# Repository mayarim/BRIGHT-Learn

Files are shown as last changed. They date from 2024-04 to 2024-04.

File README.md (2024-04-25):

# BRIGHT-Learn: Building Responsive Interactions for Growth, Healing, and Therapeutic Learning
### Custom-designed toy for a developmentally disabled child in order to facilitate comfort and enjoyment of occupational therapy activities.

Marin_Poster

## Source code: 
I used FastLED and SerialMP3Player Arduino libraries and wrote a program, Game.ino, integrating these into a game loop. The toy welcomes Marin to teh game, then prompts her to press the button of a random color. If she pressees the correct one, then the toy says "Good job" and a song plays to reward her. If she presses the incorrect one, the lights guide her towards the correct section. Currently, the code is rather disorganized, but future plans include re-factoring to create a "color" struct with various fields and filepaths in order to streamline readability. Additionally, more code will be introduced in later iterations to make the game loop more exciting and engaging. 

## 3D Models: 
The physical casing for the toy was constructed using a modular design of six "box segment" pieces around one "pie core" piece. The central core piece has columns that hold a stand for the speaker to rest on, so that it can be closer to the lid and allow more sound to pass through. All 3D models were created in Solidworks. The lid was laser cut from 1/8" plywood, then painted with a different color for each of six sections. In order to let the 3D strip lights show through from the inside, small "window" slots were cut out, and corresponding "windows" were cut out of 1/8" clear acrylic and press fit inside to make the lights visible. The cad_models folder includes all .stl and .sldprt files of 3D-printed parts, .dxf files for laser-cut parts, and a .sldasm file showing the assembly. 

## Components used: 
* Arduino Mega 2650: https://store.arduino.cc/products/arduino-mega-2560-rev3
  


* LM386 Audio Amplifier https://www.ti.com/lit/ds/symlink/lm386.pdf
  


* HiLetgo GD3300 UART Control Serial MP3 Music Player Module https://github.com/salvadorrueda/SerialMP3Player



* BTF-LIGHTING WS2812B RGB ECO LED Strip https://github.com/FastLED/FastLED/



* Arcade-style push-buttons



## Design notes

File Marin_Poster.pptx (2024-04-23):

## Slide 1

BRIGHT Learn
Building Responsive Interactions for Growth, Healing, and Therapeutic Learning
Mayari Merchant, John Board, Ph.D.
Duke University - Electrical & Computer Engineering

Motivation

There are many benefits to using light, music, and color in stimulating children with developmental disabilities.
The client, Marin Merchant, is a 12-year-old child with special needs, who is learning the colors during occupational therapy. She has trouble with fine motor skills, including dexterity with her fingers and movement-to-target accuracy. This project aims to use a combination of music and lights to teach Marin the colors, while challenging her coordination.
One problem with existing methods of teaching Marin the colors is the lack of interaction. Thus, a feedback input and output system was prioritized in the design.
Marin’s parents proposed the creation of a toy that integrates motor skills, decision-making, problem-solving, and color recognition. They expressed desire to make the toy robust against physical force, easy to turn on and off, and to not be battery-powered. They also suggested an element of familiarity be included.

Circuitry & Connectivity

- An Arduino Mega 2560 was selected as the microcontroller due to its large number of pinouts for greater connectivity (Fig 1).
- Input from pushbuttons signals the Arduino to light up LEDs with appropriate color and trigger audio event corresponding to the color.
- Audio is produced via a TX/RX SD-card reader that communicates with the Arduino to select an .mp3 file and play it from speaker.
- This audio output is routed through the LM386 amplifier to speaker for a more robust sound.
- The LED strip was noted to draw up to 2A of current, which exceeds the Arduino pinout capability. Thus an L7805 voltage regulator was introduced to provide an additional power source independent of the Arduino.
- Code used to program the Arduino is available at https://github.com/mayarim/BRIGHT-Learn

Physical Casing

- A modular design for the base of the toy was created, for ease of 3D printing (Fig 2).
- The lid was laser-cut from wood, with acrylic “windows” press-fit into each section to display the LED strip lights inside. The lid was painted such that each segment had an associated color.
- Colored push-buttons were mounted into holes in the lid, allowing external input to system.
- Issues included tolerancing the edges and corners, modifying the design for new components as they were added, adjusting the height. Iterative design was essential to creating a viable final product.
- In order to make the speaker more audible, a column was introduced, with a stand for the speaker to sit on. A hollow cylinder (not pictured) was fit over it to further amplify the sound.
- Threaded inserts were heat-set into slots in each segment, so that bolts were not needed when screwing down the lid, facilitating removing and replacing the lid for maintenance as necessary.

Design

Conclusion

- In

Figure 1: 3D Model assembly of components making the base of the part. Parts were individually 3D-printed, then press-fit together, then the cracks were sealed using a soldering iron.

Slot for screw to fit in to hold down lid

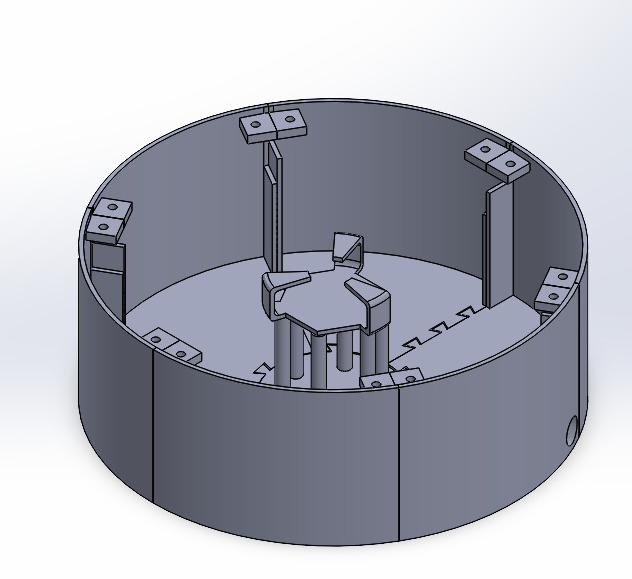
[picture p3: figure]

Future Directions

Additional considerations for future iterations of this project:
- Waterproofing design with a sealant
- Alternate versions of the arcade-style buttons would be used that have LEDs
- A volume knob, possibly realized using a potentiometer, could be implemented for comfort of the client’s parents.
- On-off switch to power device off without unplugging

Space for LED strip to fit in

Stand for speaker

Dovetail jointing mechanism

Slot for power cord

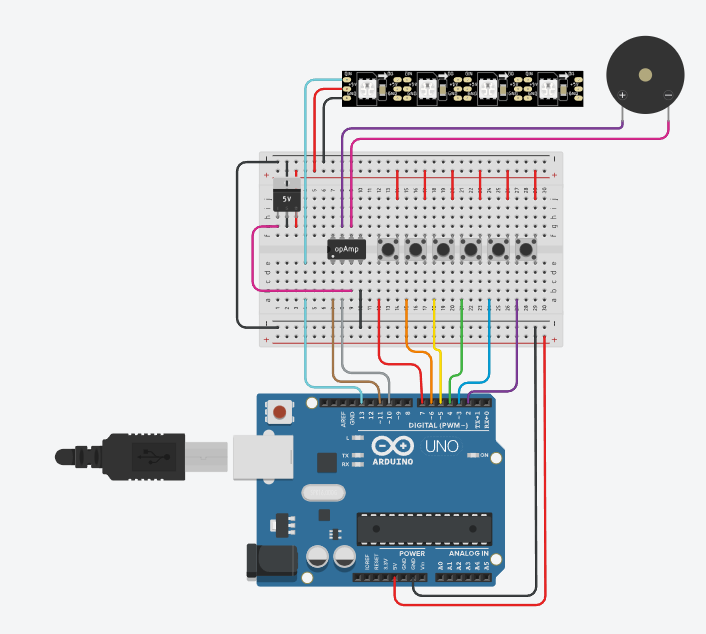
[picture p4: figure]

1. Arduino Mega 2560 was used in the project but an Arduino Uno is pictured here.

8 Ohm Speaker

Tricolor LED Array

Figure 2: Block diagram of circuit components:

References

https://docs.arduino.cc/hardware/mega-2560/ (https://github.com/salvadorrueda/SerialMP3Player)
https://github.com/FastLED/FastLED/ (https://github.com/salvadorrueda/SerialMP3Player)
https://github.com/salvadorrueda/SerialMP3Player
https://www.ti.com/lit/ds/symlink/lm386.pdf
https://www.st.com/resource/en/datasheet/l78.pdf

Array of pushbuttons (colors not pictured)

SD-card reader & LM386 Audio Amplifier

Arduino Mega 2560¹

L7805 5V Voltage Regulator

Acknowledgements

Marin Merchant for motivation and encouragement.
Sarika and Birju Merchant for proposing the idea.
Mohamed Ismail for advice with CAD tools and brainstorming.
Christopher Bingham for support with equipment.
Prof. John Board for technical advice and guidance.

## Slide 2

BRIGHT Learn
Building Responsive Interactions for Growth, Healing, and Therapeutic Learning
Mayari Merchant, John Board, Ph.D.
Duke University - Electrical & Computer Engineering

Motivation

There are many benefits to using light, music, and color in stimulating children with developmental disabilities.
The client, Marin Merchant, is a 12-year-old child with special needs, who is learning the colors during occupational therapy. She has trouble with fine motor skills, including dexterity with her fingers and movement-to-target accuracy. This project aims to use a combination of music and lights to teach Marin the colors, while challenging her coordination.
One problem with existing methods of teaching Marin the colors is the lack of interaction. Thus, a feedback input and output system was prioritized in the design.
Marin’s parents proposed the creation of a toy that integrates motor skills, decision-making, problem-solving, and color recognition. They expressed desire to make the toy robust against physical force, easy to turn on and off, and to not be battery-powered. They also suggested an element of familiarity be included.

Design Plan

Physical Casing

Figure 1: 3D Model assembly of components making the base of the part. Parts were individually 3D-printed, then press-fit together, then the cracks were sealed using a soldering iron.

Slot for screw to fit in to hold down lid

Space for LED strip to fit in

Stand for speaker

Dovetail jointing mechanism

Slot for power cord

Play-Flow

- Base of Toy: modular design, for ease of 3D printing (Fig 1).
- Lid: laser-cut from wood, with acrylic “windows” press-fit into each section to display the LED strip lights inside.
- Colored push-buttons: mounted into holes in the lid, allowing external input to system.
- Speaker: Central column with a stand for the speaker to sit on. A hollow cylinder (not pictured) was fit over it to amplify the sound.

Power-On

Startup Audio and Light Sequence

Corresponding Audio and Light Sequence Plays

Press Colored Button

Prompt a Random Color, Wait for Button-Press

If Correct: Song Plays

If Incorrect: Lights Guide Towards Color

Issues: tolerancing the edges and corners, modifying the design for new components as they were added, adjusting the height. Iterative design was essential to creating a viable final product.
Ease of use: Power on/off controlled by plugging in power cord, lid easily unscrewed for removal, Threaded inserts were heat-set into slots in each segment, so that bolts were not needed when screwing down the lid, facilitating removing and replacing the lid for maintenance as necessary.

Circuitry and Connectivity

8 Ohm Speaker

Tricolor LED Array

L7805 Voltage Regulator

Array of colored pushbuttons

SD-card reader & LM386 Audio Amplifier¹

Arduino Mega 2560²

Figure 2: Block diagram of circuit components:
1. SD-card reader and LM386 Audio Amplifier are separate modules but grouped together here.
2. Arduino Mega 2560 was used in the project but an Arduino Uno is pictured here.

Power consumption: LED strip was noted to draw up to 2A of current, which exceeds the Arduino pinout capability.
  - Thus, an L7805 voltage regulator was introduced to provide an additional power source independent of the Arduino.
Code used to program the Arduino is available at https://github.com/mayarim/BRIGHT-Learn
  - Includes code from Arduino libraries FastLED and SerialMP3Player

Future Directions

Additional considerations for future iterations of this project:
- Waterproofing design with a sealant
- Alternate versions of the arcade-style buttons would be used that have LEDs
- A volume knob, possibly realized using a potentiometer, could be implemented for comfort of the client’s parents.
- On-off switch to power device off without unplugging

Interview with client, parents, and occupational therapists

Evaluation of Available Parts and Resources

- Microcontroller: Arduino Mega 2560 due to large number of pinouts for greater connectivity (Fig 2).
- Pushbutton input: signals Arduino to light up LEDs and trigger audio event corresponding to the color.
- Audio: produced via a TX/RX SD-card reader that communicates with the Arduino to select an .mp3 file and play it from speaker.
  - Audio output is routed through LM386 amplifier to speaker for more robust sound.

References

https://docs.arduino.cc/hardware/mega-2560/ (https://github.com/salvadorrueda/SerialMP3Player)
https://github.com/FastLED/FastLED/ (https://github.com/salvadorrueda/SerialMP3Player)
https://github.com/salvadorrueda/SerialMP3Player
https://www.ti.com/lit/ds/symlink/lm386.pdf
https://www.st.com/resource/en/datasheet/l78.pdf

Design of Assembly

Join Physical Components

Integration

Logic Flow Outline

Program and Connect Arduino

Acknowledgements

Marin Merchant for motivation and encouragement.
Sarika and Birju Merchant for proposing the idea.
Mohamed Ismail for advice with CAD tools and brainstorming.
Christopher Bingham for support with equipment.
Prof. John Board for technical advice and guidance.

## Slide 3

BRIGHT Learn
Building Responsive Interactions for Growth, Healing, and Therapeutic Learning
Mayari Merchant, John Board, Ph.D.
Duke University - Electrical & Computer Engineering

Motivation

There are many benefits to using light, music, and color in stimulating children with developmental disabilities.
The client, Marin Merchant, is a 12-year-old child with special needs, who is learning the colors during occupational therapy. She has trouble with fine motor skills, including dexterity with her fingers and movement-to-target accuracy. This project aims to use a combination of music and lights to teach Marin the colors, while challenging her coordination.
One problem with existing methods of teaching Marin the colors is the lack of interaction. Thus, a feedback input and output system was prioritized in the design. Furthermore, the client’s older sister’s voice was used in the audio output for familiarity and enjoyment.

Components

Physical Components:
- Modular design of casing (Fig. 1)
- Lid was laser-cut from wood, with acrylic “windows” press-fit into each section to display the LED strip lights inside.
- Colored push-buttons were mounted into holes in the lid, allowing external input to system.
Circuitry:
- An Arduino Mega 2560 was selected as the microcontroller due to its large number of pinouts for greater connectivity.
- Input from pushbuttons signals Arduino to light up LEDs with appropriate color and trigger an audio event.
- Audio is produced via a TX/RX SD-card reader that communicates with the Arduino to select an .mp3 file and play it from speaker.
- This audio output is routed through the LM386 amplifier to speaker for a more robust sound.
- Code used to program the Arduino is available at https://github.com/mayarim/BRIGHT-Learn

Challenges, Trade-offs

Issues included tolerancing the edges and corners, modifying the design for new components, physically assembling parts.
Design Criteria: Robust against physical force, easy to turn on and off,

Conclusion

- In

Design

Figure 1: Block diagram of circuit components:

8 Ohm Speaker

Tricolor LED Array

Array of pushbuttons (colors not pictured)

L7805 5V Voltage Regulator – to allow LEDs and speaker to be powered from outlet rather than Arduino for greater power output

LM386 Audio Amplifier

Arduino Mega 2560¹: Programmable microcontroller with many pinout connectivity capabilities.

Figure 2: 3D Model assembly of components making the base of the part. Parts were individually 3D-printed, then press-fit together, then the cracks were sealed using a soldering iron.

Slot for screw to fit in to hold down lid

Space for LED strip to fit in

Stand for speaker

Slot for power cord

1. Arduino Mega 2560 was used in the project but an Arduino Uno is pictured here.

Future Directions

Additional considerations for future iterations of this project:
- Waterproofing design with a sealant
- Alternate versions of the arcade-style buttons would be used that have LEDs
- A volume knob, possibly realized using a potentiometer, could be implemented for comfort of the client’s parents.
- On-off switch to power device off without unplugging

References

https://docs.arduino.cc/hardware/mega-2560/ (https://github.com/salvadorrueda/SerialMP3Player)
https://github.com/FastLED/FastLED/ (https://github.com/salvadorrueda/SerialMP3Player)
https://github.com/salvadorrueda/SerialMP3Player
https://www.ti.com/lit/ds/symlink/lm386.pdf
https://www.st.com/resource/en/datasheet/l78.pdf

Acknowledgements

Marin Merchant for motivation and encouragement.
Sarika and Birju Merchant for proposing the idea.
Mohamed Ismail for advice with CAD tools and brainstorming.
Christopher Bingham for support with equipment.
Prof. John Board for technical advice and guidance.

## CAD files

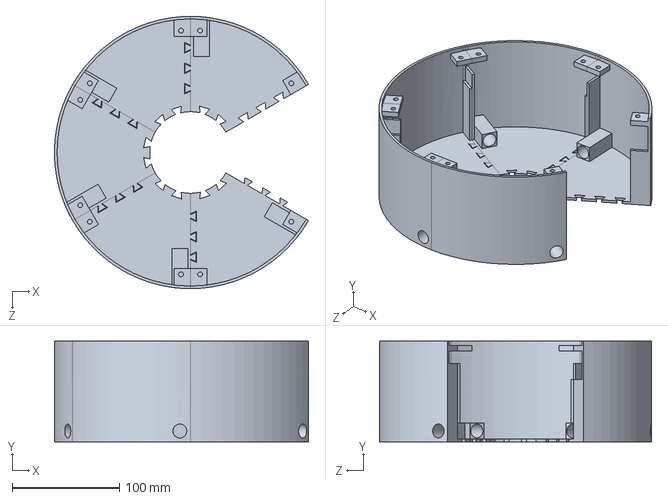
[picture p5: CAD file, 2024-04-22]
cad_models/PIE.SLDASM
236.9 x 93.7 x 254.0 mm
Box-segment_1 x 5

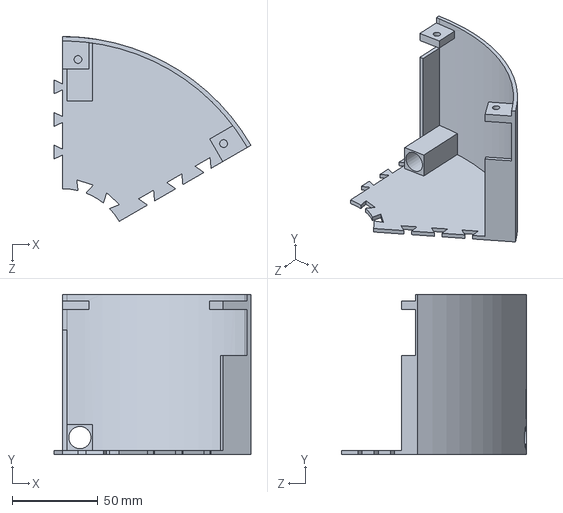
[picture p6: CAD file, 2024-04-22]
cad_models/Box-segment_1.SLDPRT
115.1 x 93.7 x 108.0 mm

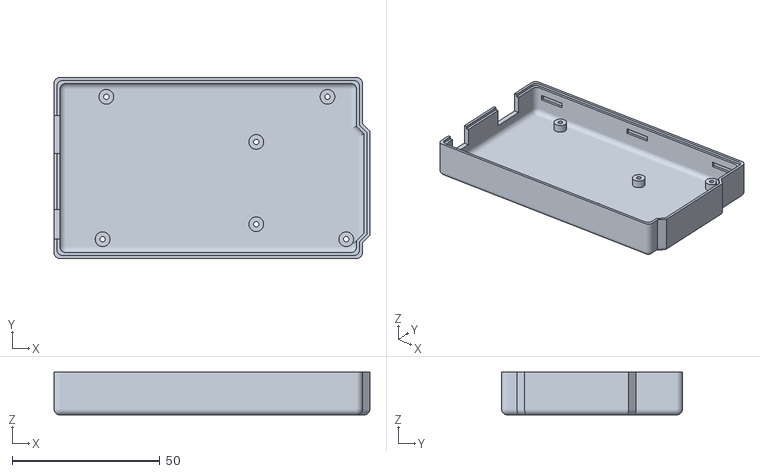
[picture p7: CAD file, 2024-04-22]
cad_models/arduino_mega_bottom.stl
107.1 x 61.3 x 14.5

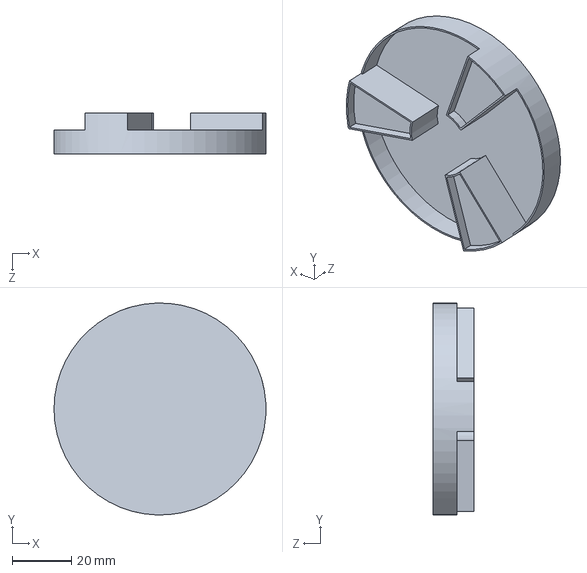
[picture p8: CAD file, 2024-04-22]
cad_models/center piece.SLDPRT
71.4 x 71.3 x 13.7 mm

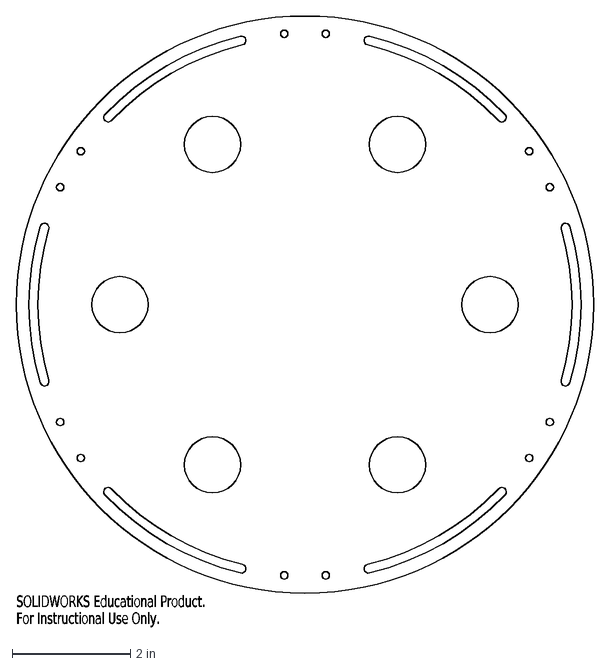
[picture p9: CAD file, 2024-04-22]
cad_models/pie_lid_windows.DXF
SOLIDWORKS Educational Product.
For Instructional Use Only.

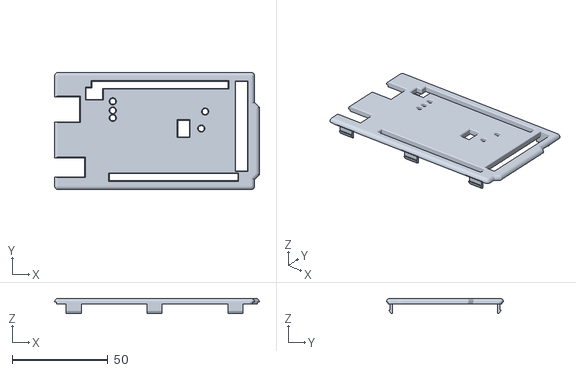
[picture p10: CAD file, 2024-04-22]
cad_models/arduino_mega_top.stl
107.1 x 61.3 x 8.00

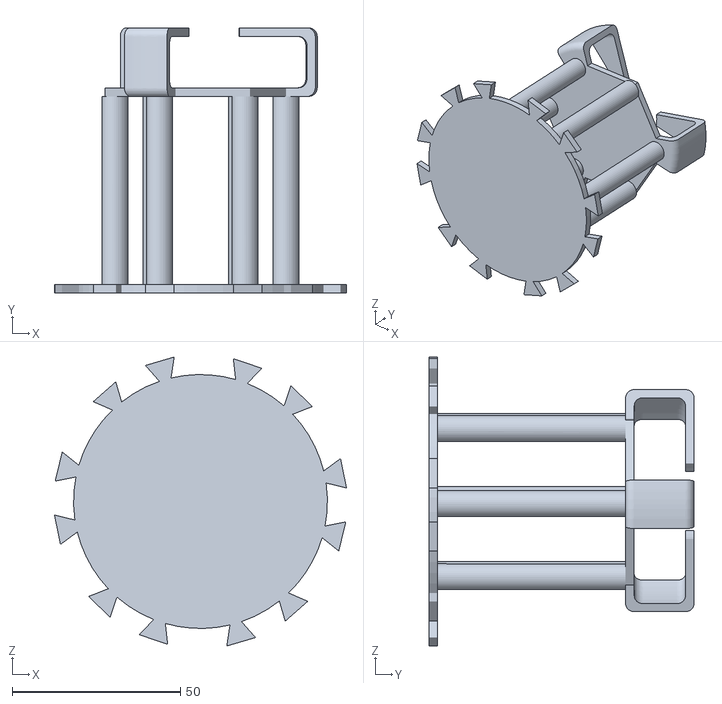
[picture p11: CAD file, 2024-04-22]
cad_models/pie_core_speaker_house.STL
86.7 x 78.7 x 85.8

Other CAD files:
cad_models/windows.SLDPRT
cad_models/windows.DXF

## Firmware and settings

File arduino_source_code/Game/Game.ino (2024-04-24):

#include "SerialMP3Player.h"
#include <FastLED.h>
//#include <PCM.h>

//LED stuff 
#define LED_PIN 47
#define NUM_LEDS 50

//pin definitions 
#define TX 11 // but actually connect RX to 11 
#define RX 10 // and TX to 10 
#define RED_BUTTON 31 //24
#define ORANGE_BUTTON 30 //26
#define YELLOW_BUTTON 28 //28
#define GREEN_BUTTON 29 //30
#define BLUE_BUTTON 26 //32
#define PURPLE_BUTTON 27 //34

//mp3 file definitions

#define GREEN_TRACK 1
#define BLUE_TRACK 2
#define RED_TRACK 3 
#define ORANGE_TRACK 4
#define YELLOW_TRACK 5
#define PURPLE_TRACK 6 
#define PROMPT_YELLOW 7 
#define PROMPT_PURPLE 8 
#define PROMPT_ORANGE 9
#define TRY_AGAIN 10 
#define COME_LET_US 11 
#define CRAYON_TO_PAPER 12 
#define COLORS_IN_BOX 13 
#define HI_MARIN_LETS_PLAY 14 
#define PROMPT_GREEN 15 
#define HI_MARIN_DO_YOU_WANT 16 
#define GOOD_JOB 17 
#define PROMPT_RED 18 
#define PROMPT_BLUE 19 

#define RED_START 0
#define ORANGE_START 8
#define YELLOW_START 16 
#define GREEN_START 24
#define BLUE_START 32 
#define PURPLE_START 40


#define STARTUP_TIME 20 //20sec for startup before game starts playing 
#define LETS_PLAY_LENGTH 200 
#define COLOR_SONG_LENGTH 300 //35 sec for color song instrumental 
#define PROMPT_WINDOW 15000

//void red(); void orange(); void yellow(); void green(); void blue(); void purple(); 

SerialMP3Player mp3(RX, TX);

CRGB leds[NUM_LEDS];

CRGB::HTMLColorCode COLORS[6] = {CRGB::Red, CRGB::OrangeRed, CRGB::YellowOrange, CRGB::Green, CRGB::Blue, CRGB::Purple};
int COLOR_TRACKS[6] = {RED_TRACK, ORANGE_TRACK, YELLOW_TRACK, GREEN_TRACK, BLUE_TRACK, PURPLE_TRACK};
int COLOR_BUTTONS[6] = {RED_BUTTON, ORANGE_BUTTON, YELLOW_BUTTON, GREEN_BUTTON, BLUE_BUTTON, PURPLE_BUTTON};
String COLOR_NAMES[6] = {"red", "orange", "yellow", "green", "blue", "purple"}; 
int COLOR_BOUNDS[6] = {RED_START, ORANGE_START, YELLOW_START, GREEN_START, BLUE_START, PURPLE_START}; 
int COLOR_OPPOSITE_LOCS[6] = {(GREEN_START + 4), (BLUE_START + 4), (PURPLE_START + 4), (RED_START + 4), (ORANGE_START + 4), (YELLOW_START + 4)};
typedef void (*ColorFunction)();
int COLOR_PROMPTS[6] = {PROMPT_RED, PROMPT_ORANGE, PROMPT_YELLOW, PROMPT_GREEN, PROMPT_BLUE, PROMPT_PURPLE};
int WELCOME_MESSAGES[2] = {HI_MARIN_LETS_PLAY, HI_MARIN_DO_YOU_WANT};
int COLOR_SONG[3] = {COME_LET_US, CRAYON_TO_PAPER, COLORS_IN_BOX};

char c;  // char from Serial
char cmd = ' ';
char cmd1 = ' ';
static int target_color; 
static int last_prompt; 
static bool prompt_mode; 
int track_num;
static uint8_t timer;
static int turn_off_time; 

void setup() {
  FastLED.addLeds<WS2812, LED_PIN, GRB>(leds, NUM_LEDS);
  FastLED.setMaxPowerInVoltsAndMilliamps(5, 500);
  FastLED.clear();
  FastLED.show();
  
  for(int i = 0; i < 6; i++){
    pinMode(COLOR_BUTTONS[i], INPUT);
  }
  
  mp3.showDebug(1);       // print what we are sending to the mp3 board.

  Serial.begin(9600);     // start serial interface
  mp3.begin(9600);        // start mp3-communication
  delay(100);             // wait for init

  mp3.sendCommand(CMD_SEL_DEV, 0, 2);   //select sd-card
  delay(100);             // wait for init

  randomSeed(analogRead(3));
  
  startup(); 
  
}




// the loop function runs over and over again forever
void loop() {
//  delay(50); 

  timer = millis();

  if(timer > turn_off_time){
    FastLED.clear();
  }

  if(timer > 10000 && timer < 20000 && prompt_mode == false) {
    prompt_mode = true; 
    prompt(3);
  }

  if(timer > 20000 && timer < 30000 && prompt_mode == false) {
    prompt_mode = true; 
    prompt(1);
  }

  if(prompt_mode == false) {
    for(int color_id = 0; color_id < 5; color_id++){
      if(digitalRead(COLOR_BUTTONS[color_id]) == HIGH){
        Serial.print("color pressed non prompt mode - ");
        Serial.println(COLOR_NAMES[color_id]);
        color_func(color_id);
      }
    } 
    if(digitalRead(RED_BUTTON) == HIGH && digitalRead(PURPLE_BUTTON) == HIGH){
      Serial.println("fine okay purple"); 
      color_func(5);
    }
  }
   
 
  if (Serial.available()) {
    c = Serial.read();
    Serial.print(c);
    decode_c(); // Decode c.
    Serial.print("done decoding: ");
    Serial.println(c);
  }
  // Check for the answer.
  if (mp3.available()) {
    Serial.println(mp3.decodeMP3Answer()); // print decoded answers from mp3
  } 



  if(prompt_mode == false) {
    //if not in prompt_mode, normal gameplay 
//    for(int color_id = 0; color_id < 5; color_id++){
//      if(digitalRead(COLOR_BUTTONS[color_id]) == HIGH){
//        Serial.print("time: ");
//        Serial.println(timer);
//        color_func(color_id);
//      }
//    }

    //if it's been a while since we last prompted, prompt 
//    if(timer > last_prompt + PROMPT_WINDOW){
//      prompt_mode = true; 
//      last_prompt = timer; 
//      Serial.print("time to prompt again... prompting at time: ");
//      Serial.println(timer);
//      prompt(random(0,5));
//    } 
  }


  if(prompt_mode == true){
      if(digitalRead(COLOR_BUTTONS[target_color]) == HIGH){
        prompt_mode = false;
        celebrate(target_color); //blocking 
        Serial.println("yay Marin!");
      }
      for(int color_id = 0; color_id < 5; color_id++){
        if(digitalRead(COLOR_BUTTONS[color_id]) == HIGH && color_id != target_color){
          Serial.print("detected color: ");
          Serial.println(COLOR_NAMES[color_id]);
          mp3.play(COLOR_TRACKS[color_id]);
          delay(1000);
          mp3.play(TRY_AGAIN);
          blocking_guide(target_color); //guide to target color 
        }
      }

//      if(timer > last_prompt + PROMPT_WINDOW){
//        //prompt expired 
//        Serial.print("exiting prompt mode at time: ");
//        Serial.println(timer);
//        last_prompt = timer; 
//        prompt_mode = false; 
//      }
  }


 

} // end loop()




void startup() {
  Serial.println("startup!!"); 
  rainbow_all();
  mp3.play(WELCOME_MESSAGES[random(0,1)]);
  target_color = random(0,5);
  delay(2000);
//  blocking_guide(target);
  last_prompt = millis();
  prompt_mode = true; 
  prompt(target_color);
  Serial.println("done startup :)");
  return; 
}

void blocking_guide(int color_id) {
  CRGB::HTMLColorCode color = COLORS[color_id];
  int start_loc = COLOR_OPPOSITE_LOCS[color_id];
  FastLED.clear();
  FastLED.show();
  int delay_time = 10; 
  int right_led = start_loc+1;
  int left_led = start_loc;  
  
  if(left_led > right_led){
    Serial.println("uh oh");
  } else Serial.println("yay ");
  
  for(int i = 0; i <= (NUM_LEDS/2); i++){
    leds[left_led] = CRGB(color);
    leds[right_led] = CRGB(color);
    right_led ++;
    left_led --;
    if(left_led < 0){
      left_led = NUM_LEDS;
    } 
    if(right_led > NUM_LEDS){
      right_led = 0;
    }
    FastLED.show();
    delay(100);
    
  }
  
}

void prompt(int target_color){
  Serial.println(target_color);
  mp3.play(COLOR_PROMPTS[target_color]);
  all_color(target_color);
  delay(1000);
  FastLED.clear();
  FastLED.show();
}

void blink(int color_id) {
  CRGB::HTMLColorCode color = COLORS[color_id];
  static uint8_t wait = 50;
  static unsigned long lastUpdate = 0;
  static int currentLed = 0; 
 
  unsigned long now = millis();
  if (now > lastUpdate+delay) {
    leds[currentLed] = color;
    FastLED.show();   
    currentLed = currentLed>NUM_LEDS ? 0 : currentLed+1;
    lastUpdate = now;
  }
}

void celebrate(int color_id){
  all_color(color_id);
  mp3.play(GOOD_JOB);
  delay(1000);
  mp3.play(COLOR_TRACKS[color_id]);
  delay(500);
  mp3.play(COLOR_SONG[0]);
  delay(4000);
  mp3.play(COLOR_TRACKS[color_id]);
  delay(200);
  mp3.play(COLOR_SONG[1]);
  delay(11000);
  mp3.play(COLOR_TRACKS[color_id]);
  delay(200);
  mp3.play(COLOR_SONG[2]);
  delay(5000);
  FastLED.clear();
  FastLED.show();
  return; 
}


void rainbow_all(){
  for(int i = 0; i< NUM_LEDS; i++){
    if( i >= RED_START && i < ORANGE_START){
       leds[i] = CRGB(255,0,0);
    } else if(i >= ORANGE_START && i < YELLOW_START){
//      leds[i] = CRGB(255,140,0); 
       leds[i] = CRGB::Orange;
    } else if(i >= YELLOW_START && i < GREEN_START) {
       leds[i] = CRGB(255,255,0);
    } else if(i >= GREEN_START && i < BLUE_START) {
       leds[i] = CRGB(0,255,0);
    } else if(i >= BLUE_START && i < PURPLE_START) {
       leds[i] = CRGB(0,0,255);
    } else if(i >= PURPLE_START && i < NUM_LEDS) {
       leds[i] = CRGB(200,0,200);
    }  
    FastLED.show();
  }
}

void all_color(int color_id){
  CRGB::HTMLColorCode color_code = COLORS[color_id];
  FastLED.clear();
  FastLED.setBrightness(100);
  for(int i = 0; i< NUM_LEDS; i++){
    leds[i] = color_code; 
    FastLED.show();
  }
  return; 
}

void color_func(int color_id){
    Serial.print("prompt mode? ");
    Serial.print(prompt_mode);
    Serial.print("  color: ");
    Serial.println(COLOR_NAMES[color_id]);
    all_color(color_id);
    mp3.play(COLOR_TRACKS[color_id]);
    return;
}


void menu(char op, int nval) {
  // Menu
  switch (op) {
    case '\n':
      Serial.println("new line");
      break;
    case '?':
    case 'h':
      Serial.println("SerialMP3Player Basic Commands:");
      Serial.println(" ? - Display Menu options. ");
      Serial.println(" P01 - Play 01 file");
      Serial.println(" F01 - Play 01 folder");
      Serial.println(" S01 - Play 01 file in loop");
      Serial.println(" V01 - Play 01 file, volume 30");
      Serial.println(" p - Play");
      Serial.println(" a - pause");
      Serial.println(" s - stop ");
      Serial.println(" > - Next");
      Serial.println(" < - Previous");
      Serial.println(" + - Volume UP");
      Serial.println(" - - Volume DOWN");
      Serial.println(" v15 - Set Volume to 15");
      Serial.println(" c - Query current file");
      Serial.println(" q - Query status");
      Serial.println(" x - Query folder count");
      Serial.println(" t - Query total file count");
      Serial.println(" r - Reset");
      Serial.println(" e - Sleep");
      Serial.println(" w - Wake up");
      break;

    case 'p':
//      Serial.println("play fr");
//      mp3.play();
      prompt_mode = true;
      target_color = random(0,5);
      prompt(target_color);
      break;

    case 'e': 
      prompt_mode = false;
      break;

    case 'a':
      Serial.println("Pause");
      mp3.pause();
      break;

    case 's':
      Serial.println("Stop");
      mp3.stop();
      break;


    case 'r': 
      color_func(0);
//      red
      break;
      Serial.println("red");
      mp3.play(RED_TRACK);
      break;

    case 'o': 
//      orange();
      color_func(1);
      break;
      Serial.println("orange from Serial");
      mp3.play(ORANGE_TRACK);
      Serial.println("done orange");
      break;

    case 'y': 
      color_func(2);
//      yellow();
      break; 

    case 'g':
      color_func(3); 
//      green();
      break;
      Serial.println("green"); 
      mp3.play(GREEN_TRACK);
      break; 

    case 'b':
      color_func(4);
//      blue();
      break;
      Serial.println("blue");
      mp3.play(BLUE_TRACK);
      break;

    case 'u': 
      color_func(5);
//      purple();
      break;
      Serial.println("purple"); 
      mp3.play(PURPLE_TRACK);
      break; 

    case 'c':
      FastLED.clear();
      break;

    case 'l':
      celebrate(random(0,5));
      break;
  }
  return;
}

void decode_c() {
  // Decode c looking for a specific command or a digit

  // if c is a 'v', 'P', 'F', 'S' or 'V' wait for the number XX
  if (c == 'v' || c == 'P' || c == 'F' || c == 'S' || c == 'V') {
    cmd = c;
  } else {
    // maybe c is part of XX number
    if (c >= '0' && c <= '9') {
      // if c is a digit
      if (cmd1 == ' ') {
        // if cmd1 is empty then c is the first digit
        cmd1 = c;
      } else {
        // if cmd1 is not empty c is the second digit
        menu(cmd, ((cmd1 - '0') * 10) + (c - '0'));
        cmd = ' ';
        cmd1 = ' ';
      }
    } else {
      // c is not a digit nor 'v', 'P', 'F' or 'S' so just call menu(c, nval);
      menu(c, 0);
    }
  }
}

/*if(digitalRead(RED_BUTTON) == HIGH){
    Serial.println("red button");
    red(); 
  }

  if(digitalRead(ORANGE_BUTTON) == HIGH){
    Serial.println("orange button");
    orange();
  } 

  if(digitalRead(YELLOW_BUTTON) == HIGH){
    Serial.println("yellow button");
    yellow();
  }

  if(digitalRead(GREEN_BUTTON) == HIGH){
    Serial.println("green button");
    green();
  }

  if(digitalRead(BLUE_BUTTON) == HIGH){
    Serial.println("blue button");
    blue(); 
  }
  
  if(digitalRead(PURPLE_BUTTON) == HIGH){
    Serial.println("purple button");
    purple(); 
  }

  if(Serial.available()){
    int old_track_num = track_num;
    track_num = (int)Serial.read() - 64;
    if(track_num >= 0 && track_num < 26){
        Serial.println(track_num); 
        mp3.play(track_num);
    } 
    if(track_num == (110 - 64)) {
      old_track_num++;
      Serial.println(old_track_num); 
      mp3.play(old_track_num);
    }

  }
  */

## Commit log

2024-04-22 adding code, cad files, audio files
    [Box-seg-pwr_slot_taller.SLDPRT, Box-segment_1.SLDPRT, PIE.SLDASM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]
2024-04-25 adding arduino libraries
